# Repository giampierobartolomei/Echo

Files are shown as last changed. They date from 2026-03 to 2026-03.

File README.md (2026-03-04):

# Echo – An AI‑based Toy for Symbolic Play Recognition and Data Collection 

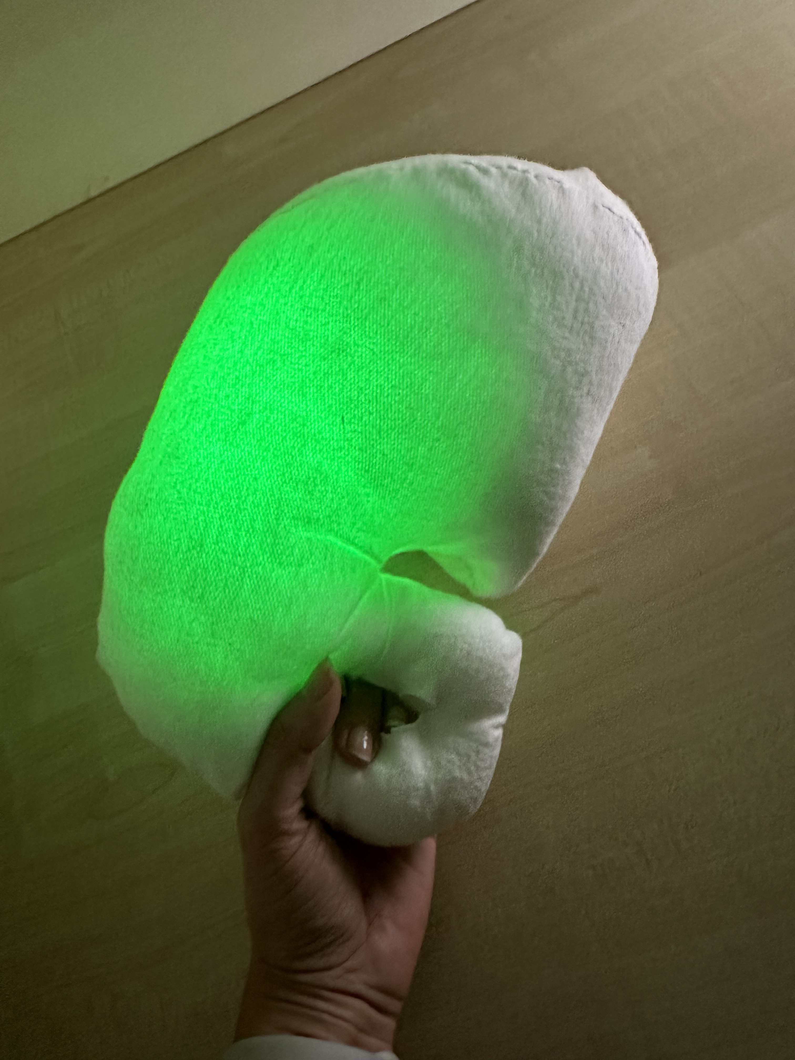
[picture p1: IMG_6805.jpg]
Echo Prototype


---

## Overview
**Echo** is an intelligent toy designed to recognize and log **symbolic play activities** in children with Autism Spectrum Conditions.  
It combines onboard sensors, real‑time classification, and a custom Android application to support both **therapy** and **data collection** within the IM‑TWIN research framework.

Echo detects and classifies manipulative play gestures using embedded machine‑learning models trained on inertial data. The system provides **sound and light feedback**, while also logging structured data for offline analysis.

---

## Hardware Setup
- **Microcontroller:** ESP32 (with integrated MPU6050 IMU)  
- **Sensors:** MPU9265 sensor: 3‑axis accelerometer (±2 g) and gyroscope (±500 °/s), tilt angles 0–360°  
- **Outputs:** LEDs and speaker for multimodal feedback  
- **Prototype files:** `.fzz` breadboard, schematic, and PCB layouts are included in the electronics/ folder.  
- **Audio:** `mp3/` folder includes `.mp3` files for feedback behavior, please copy this folder in a microSD and put into the DFplayermini module.

---

## Firmware and Algorithms

### Folders and Functions
The firmware/ directory contains the Arduino sketch for Echo. This sketch integrates the motion‑classification model (already compiled into model.h) and controls the LEDs and DFPlayerMini. Simply open the .ino file in the Arduino IDE, install the required libraries, and upload it to your ESP32. No additional training is needed – the decision‑tree model is embedded and ready to run.

### Signal and Range
- Accelerometer: ±2 g (gravity compensation active)  
- Gyroscope: ±500 °/s  
- Tilt angles: 0–360°

## Android App (APK)

The app/ folder includes a prebuilt Android application (EchoApp.apk). Install this APK directly on an Android device (Android 8+ recommended). 

### Features
- Real‑time plotting of **tilt** and **accelerometer** data.  
- **Label selection buttons** for organizing recorded gestures.  
- Automatic creation of labeled log files.  
- Volume and LED sliders: LEDs turn on at startup, and users can control brightness and sound volume.  
- Bluetooth connection with Echo for real‑time classification feedback.

## 3D‑Printable Cover

The cover_3d/ directory provides STL files for a 3D‑printable cover/enclosure. Print the parts at 100 % scale using PLA or PETG, then assemble them around the ESP32 and DFPlayerMini according to the photographs in the folder. The cover is designed to protect the electronics and provide a child‑friendly form factor.

## Embedding

Use an e-form fabric, fill it with wadding and place the electronics in the flat base; make the led strip run over all the prototype.

## Data Workflow

1. Assemble the hardware following the electronics diagram and install the firmware from firmware/.

2. Copy the contents of the mp3/ folder onto a microSD card and insert it into the DFPlayerMini.

3. Install the EchoApp.apk on an Android device and pair it via Bluetooth with your ESP32.

4. Power on Echo. When gestures are performed, the device will classify them using the embedded model and provide audio/LED feedback.

5. Use the app to view live sensor data, adjust settings and log sessions for later analysis.

6. Export logged .csv files from the app if you wish to retrain or refine the model.

## Citations

**1. Giampiero Bartolomei, Beste Ozcan, Giovanni Granato, Gianluca Baldassarre, and Valerio Sperati. 2025. Echo: an AI-based toy to encourage symbolic play in children with Autism Spectrum Conditions. In Proceedings of the Nineteenth International Conference on Tangible, Embedded, and Embodied Interaction (TEI '25). Association for Computing Machinery, New York, NY, USA, Article 85, 1–6. https://doi.org/10.1145/3689050.3705987**  

**2. Bartolomei, G., Ozcan, B., Granato, G., Baldassarre, G., & Sperati, V. (2025). A proposal for an AI-based toy to encourage and assess symbolic play in autistic children. Behaviour & Information Technology, 44(14), 3390–3403. https://doi.org/10.1080/0144929X.2025.2523478**

---

## License
Code and documentation released under the **MIT License**.  
Audio and media assets under **CC BY 4.0**.

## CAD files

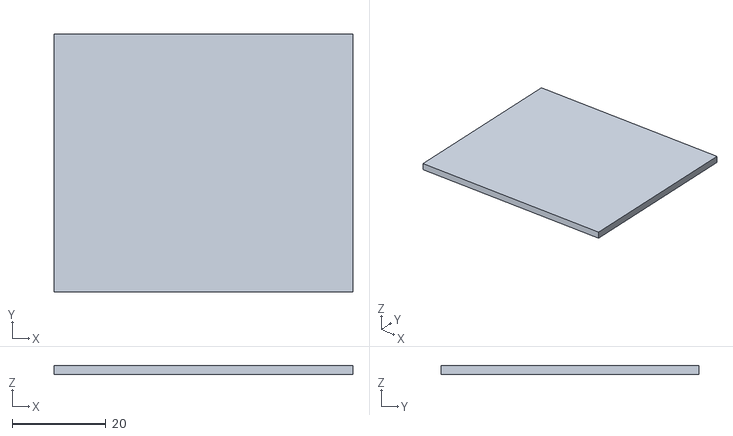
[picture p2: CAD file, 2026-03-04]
stl_file_cover/battery-cup1.stl
63.7 x 55.0 x 2.00

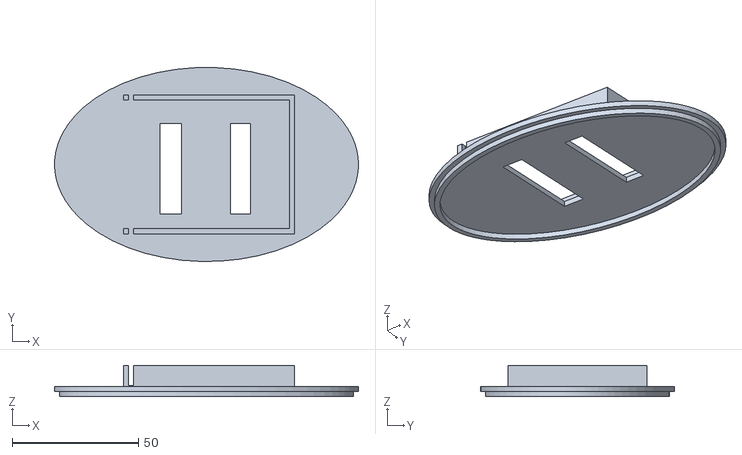
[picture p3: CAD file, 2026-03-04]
stl_file_cover/cup.stl
120.6 x 76.9 x 12.3

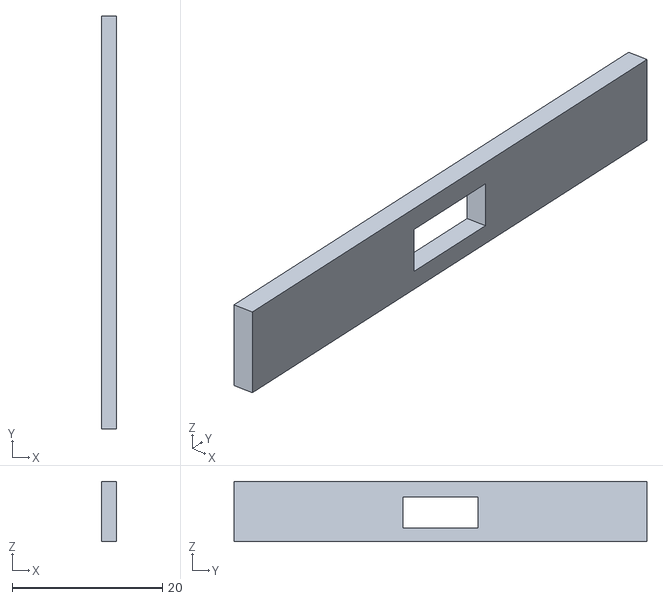
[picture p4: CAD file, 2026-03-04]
stl_file_cover/battery-cup2.stl
2.00 x 55.0 x 8.00

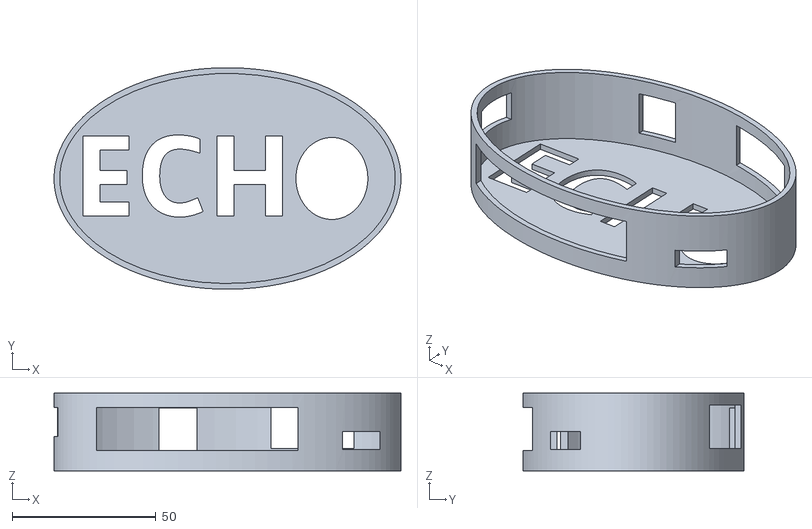
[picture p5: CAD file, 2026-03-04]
stl_file_cover/cover.stl
120.6 x 77.0 x 27.0

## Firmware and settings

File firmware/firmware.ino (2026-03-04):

//to load this code change this setting: arduino uno/Tools/Partition Scheme:HUGE APPS (3 MB no OTA/1 MB SPIFFS)
//Insert mp3 file in a folder named 'mp3' in the root path of a microSD. they are sorted by the date and hour of file uploading.
#include <BLEDevice.h>
#include <BLEUtils.h>
#include <BLEScan.h>
#include <BLEAdvertisedDevice.h>
#include <Arduino.h>
#include <arduinoFFT.h>
#include "model_alldata.h"  //change this line for test the other models
#include "Wire.h"
#include <MPU6050_light.h>
#include <BLEServer.h>
#include <deque>
#include <math.h>
#include "Bluetooth.h"
#include <Adafruit_NeoPixel.h>
#include "DFRobotDFPlayerMini.h"  //DFPlayermini_Fast can be an alternative
// CONSTANTS
#define INTERVAL 33
#define SAMPLES 16  // Number of samples processed
#define SAMPLING_FREQUENCY 30
#define CLASSIFICATION_BUFFER_SIZE 5  // Number of classification saved before to indicate wich class is the most rapresentative(Majority Voting) - DEFAULT VALUE
#define PIN_STRIP 13
#define NUMPIXELS 10
#define LED_LOG1 32 //RED
#define LED_LOG2 25 //YELLOW
#define potPin 34

//VARIABLES

//fft variables
float vReal[SAMPLES];  // Vettore per le componenti reali
float vImag[SAMPLES];  // Vettore per le componenti immaginarie
ArduinoFFT<float> FFT = ArduinoFFT<float>(vReal, vImag, SAMPLES, SAMPLING_FREQUENCY);
float features[3 * (SAMPLES / 2)];  // magnitude array that will cuncatenate fft results of the 3 features

// selected features - best 3 features ranked by a RandomForestClassifier
float feature1[SAMPLES];
float feature2[SAMPLES];
float feature3[SAMPLES];

int bufferIndex = 0;  // current index of samples saved in the buffer - from 0 to SAMPLES

// variables that store classification results
int classificationBuffer[CLASSIFICATION_BUFFER_SIZE];  // Buffer per le classificazioni
int classificationIndex = 0;                           // Saved Classification Index - from 0 to CLASSIFICATION_BUFFER_SIZE
int cbs = 5; //variable classification buffer size - 5 is default
MPU6050 mpu(Wire);
using namespace std;

// Temporal variable that defines acquisition cycles, f_s = 30 Hz; t_s = 33 ms
long prevMillis = 0;
unsigned long timestep = 0;
uint8_t timestepByte = 0;
int durata = 0;
int prev_durata = 0;
// bluetooth variables
bool identification = false;
void function_identify(bool identify);
void parse_commands(char* commands);
void function_(char* commands);
int current_function = 0;
bool send_diagnostic = false;
int lastReadValue = -1;  // BT trasmission command value

//byte data that will be sent to the Godot App
uint8_t log_values[11]; 
float x = 0;
float y = 0;
float z = 0;
float Gx = 0;
float Gy = 0;
float Gz = 0;
float Ax = 0;
float Ay = 0;
float Az = 0;
int classification = 0;
int mostFrequentClass = -1;

//Output Response Inizialization
Adafruit_NeoPixel strip = Adafruit_NeoPixel(NUMPIXELS, PIN_STRIP, NEO_GRB + NEO_KHZ800); //Led strip initialize
DFRobotDFPlayerMini player;  // Mp3 player initialize
Eloquent::ML::Port::DecisionTree clf; //if using model_all.h (with frog) micromlgen lilbrary to generate c function

//Volume settings Initializatioon
int potValue = 0;       
int volume = 0;        
int volumevalues[] = {0, 5, 10, 15, 20};

//Light intensity
int lightvalues[] = {0,32,64,128,255};
int lightvalue = 2;

void setup() {
  
  //fill the putput classification array with all -1 values, this value will be updated within the loop phase
  for (int i = 0; i < CLASSIFICATION_BUFFER_SIZE; i++) {
    classificationBuffer[i] = -1;  
  }
  
  Serial.begin(115200); //Serial comunication for debug

  // DF mini Player Inizialization (RX=16<-->TXdfmini & TX=17<-->RXdfmini)
  Serial2.begin(9600, SERIAL_8N1, 16, 17);  
  Serial.println("Connecting to DFplayer"); 
  while (!player.begin(Serial2)) {  //if dfplayer is connected the rest of the code can start to run
    Serial.print(".");
    delay(1000);
  }
  Serial.println(" DFplayer connected!");

  //Setting start Volume
  volume = 10;
  player.volume(volume);  

  //MPU9250 Inizialization
  Wire.begin();
  uint8_t status = mpu.begin();
  Serial.print(F("MPU9250 status: "));
  Serial.println(status);
  while (status != 0) {}  // if MPU is connected the rest of the code can run
  Serial.println(F("Calculating offsets, do not move MPU6050"));
  delay(1000);
  // mpu.upsideDownMounting = true; // uncomment this line if the MPU6050 is mounted upside-down
  mpu.calcOffsets();  // gyro and accelerometer
  Serial.println("Calibration Done!\n");

  //Initialization LED for comunication Android->Arduino the light up if the relative button in the app is pressed, 
  pinMode(LED_LOG1, OUTPUT);
  pinMode(LED_LOG2, OUTPUT);
  digitalWrite(LED_LOG1, LOW);  
  digitalWrite(LED_LOG2, LOW);       
  
  //last setup for BLE and LED strip
  setup_BLE_ESP32();

  //Strip led ON signal and setup
  strip.begin();
  for (int i = 0; i < strip.numPixels(); i++) {
    strip.setPixelColor(i, strip.Color(255, 0, 0));  // Accendi con un colore viola medio
  }
  strip.show();  // accensione
  delay(1500);
  for (int i = 0; i < strip.numPixels(); i++) {
    strip.setPixelColor(i, strip.Color(0, 0, 0));  // Spegni i LED
  }
  strip.show();   // Mostra i LED spenti
}

void loop() {

  //Setting the loop duration at frequency = 1/INTERVAL, this loop governate all the arduino loop function (they start and end together)
  long curMillis = millis();
  if (curMillis - prevMillis >= INTERVAL) {
    long int start = millis();
    
    // Volume Changing - ONLY if the potentiometer change its Value, the Volume of the speaker change its Value (This is important! if player.volume is called every loop, the loop duration gets bigger!!)
    potValue = analogRead(potPin);
    volume = mapfloat(potValue, 0, 4095, 0, 30);
    static int lastVolume = -1;
    if (volume != lastVolume) {
      player.volume(volume);
      lastVolume = volume;
      Serial.print("Volume updated at: ");
      Serial.println(volume);
    }

    //Sensor Readings
    mpu.update();
    x = float(mpu.getAngleX());
    y = float(mpu.getAngleY());
    z = float(mpu.getAngleZ());
    Gx = float(mpu.getGyroX());  //+- 500 deg/s
    Gy = float(mpu.getGyroY());
    Gz = float(mpu.getGyroZ());
    Ax = float(mpu.getAccX());  //+-2g
    Ay = float(mpu.getAccY());
    Az = float(mpu.getAccZ() - 1);  // -1 compensa l'effetto della gravità

    // filling samples buffer of the 3 selected features
    feature1[bufferIndex] = x;
    feature2[bufferIndex] = y;
    feature3[bufferIndex] = Gz;
    bufferIndex++;

    // Checking if the buffer is full, hen it is, the processing of the data start
    if (bufferIndex >= SAMPLES) {
      bufferIndex = 0;

      // FFT function Computation
      auto calculateFFT = [](const float input[], float magnitudes[], int offset) {
        for (int i = 0; i < SAMPLES; i++) {
          vReal[i] = input[i];
          vImag[i] = 0.0f;  // the Immaginary part is 0
        }
        FFT.compute(FFTDirection::Forward);
        FFT.complexToMagnitude();
        for (int i = 0; i < SAMPLES / 2; i++) {
          magnitudes[offset + i] = vReal[i];
        }
      };

      // FFT computation of the 3 features and concatenation in the 'features' variable.
      calculateFFT(feature1, features, 0);
      calculateFFT(feature2, features, SAMPLES / 2);
      calculateFFT(feature3, features, SAMPLES);
      
      /*for (int i = 0; i < 24; i++) {
      Serial.print("features[");
      Serial.print(i);
      Serial.print("]: ");
      Serial.println(features[i]);
    }
    */
      //Classify and saving the result in a buffer for Majority Voting
      classification = clf.predict(features);  
      classificationBuffer[classificationIndex] = classification;
      classificationIndex++;

      // When the buffer of the classification is full, the most rapresentative class is saved in the 'mostFrequentClass' variable
      if (classificationIndex >= cbs) {  //before there was CLASSIFICATION_BUFFER_SIZE
        int classCounts[4] = { 0, 0, 0, 0 };
        for (int i = 0; i < cbs; i++) { //before there was CLASSIFICATION_BUFFER_SIZE
          classCounts[classificationBuffer[i]]++;
        }
        int maxCount = 0;
        for (int i = 0; i < 4; i++) {
          if (classCounts[i] > maxCount) {
            maxCount = classCounts[i];
            mostFrequentClass = i;  //majority result
          }
        }

        // Conversion from a numerical label (0,1,2,3) to textual label for Serial Printing
        String classificationString;
        switch (mostFrequentClass) {
          case 0:
            classificationString = "AIRPLANE";
            for (int i = 0; i < strip.numPixels(); i++) {
              strip.setPixelColor(i, strip.Color(lightvalue, 0, 0));  // RED
              strip.show();                                    
            }
            player.play(1);  
            break;
          case 1:
            classificationString = "CAR";
            for (int i = 0; i < strip.numPixels(); i++) {
              strip.setPixelColor(i, strip.Color(lightvalue, 0, lightvalue));  // VIOLET
              strip.show();                                  
            }
            player.play(2);  
            break;
          case 2:
            classificationString = "FROG";
            for (int i = 0; i < strip.numPixels(); i++) {
              strip.setPixelColor(i, strip.Color(0, lightvalue, 0));  // GREEN
              strip.show();                                    
            }
            player.play(3);  
            break;
          case 3:
            classificationString = "IGNORING";
            for (int i = 0; i < strip.numPixels(); i++) {
              strip.setPixelColor(i, strip.Color(0, 0, lightvalue));  // BLUE
              strip.show();                                    
            }
            player.play(4);  
            break;
          default:
            classificationString = "UNKNOWN";  //useful for debug
            break;
        }

        //DEBUG PRINTS
        Serial.print("Activity: ");
        Serial.println(classificationString);

        classificationIndex = 0;
      }
    }
    

    // BT Transmission to Arduino
    String value = stringStreamCharacteristic->getValue();  // Simulate a reading
    if (!value.isEmpty()) {
      int readValue = atoi(value.c_str());
      if (readValue != lastReadValue) {  ///COMMAND: consecutive equal commands will not work!!!, this helps to have different commands

        if (readValue == 10){////COMMAND: Start log button will turn on the led strip (orange)
          Serial.println("Start Log");
          for (int i = 0; i < strip.numPixels(); i++) {
            strip.setPixelColor(i, strip.Color(255, 165, 0));  // Colore arancione
            strip.show();                                       
          }
          //reset all when start log is pressed
          bufferIndex=0;
          classificationIndex = 0; 
          classification = 9;
          mostFrequentClass = 9; 

        } else if (readValue == 20) {//COMMAND: Stop log button will turn on the led strip (orange)
          Serial.println("Stop Log");
          for (int i = 0; i < strip.numPixels(); i++) {
            strip.setPixelColor(i, strip.Color(255, 165, 0));  // Colore arancione
            strip.show();                                       
          }
        }  else if (readValue == 11) {///COMMAND: classification buffer size regulation (from 11 to 15)
          cbs=1;
        }  else if (readValue == 12) {
          cbs=2;
        }  else if (readValue == 13) {
          cbs=3;
        }  else if (readValue == 14) {
          cbs=4;
        }  else if (readValue == 15) {
          cbs=5;
        } else if (readValue == 21) {////COMMAND: volume intensity (from 21 to 25)
          player.volume(volumevalues[0]);
        }  else if (readValue == 22) {
          player.volume(volumevalues[1]);
        }  else if (readValue == 23) {
          player.volume(volumevalues[2]);
        }  else if (readValue == 24) {
          player.volume(volumevalues[3]);
        }  else if (readValue == 25) {
          player.volume(volumevalues[4]);
        }  else if (readValue == 31) {////COMMAND: light intensity (from 31 to 35)
          lightvalue = lightvalues[0];
        }  else if (readValue == 32) {
          lightvalue = lightvalues[1];
        }  else if (readValue == 33) {
          lightvalue = lightvalues[2];
        }  else if (readValue == 34) {
          lightvalue = lightvalues[3];
        }  else if (readValue == 35) {
          lightvalue = lightvalues[4];
        }  

        lastReadValue = readValue;  
      }
    }

    // BT Transmission to Android
    log_values[0] = static_cast<uint8_t>(mapfloat(Ax, -2, 2, 0, 255));
    log_values[1] = static_cast<uint8_t>(mapfloat(Ay, -2, 2, 0, 255));
    log_values[2] = static_cast<uint8_t>(mapfloat(Az, -2, 2, 0, 255)); 
    log_values[3] = static_cast<uint8_t>(mapAngleToByte(x));
    log_values[4] = static_cast<uint8_t>(mapAngleToByte(y));
    log_values[5] = static_cast<uint8_t>(mapAngleToByte(z));
    log_values[6] = static_cast<uint8_t>(mapfloat(Gx, -500, 500, 0, 255));
    log_values[7] = static_cast<uint8_t>(mapfloat(Gy, -500, 500, 0, 255));
    log_values[8] = static_cast<uint8_t>(mapfloat(Gz, -500, 500, 0, 255));
    log_values[9] = static_cast<uint8_t>(classification); //single classification result
    log_values[10] = static_cast<uint8_t>(mostFrequentClass); //majority voting result
    logCharacteristic->setValue(log_values, 11);
    logCharacteristic->notify();
    
    
    

    long int ende = millis();
    durata = ende - start;
    prev_durata = durata;
    Serial.print("Durata ciclo: "); //debug print for ms passed for cicle
    Serial.println(durata);
    prevMillis = curMillis;
    timestep++;

    timestepByte++;
  }
}

float mapfloat(float x, float in_min, float in_max, float out_min, float out_max) {
  return (x - in_min) * (out_max - out_min) / (in_max - in_min) + out_min;
}

float euler_to_byte(float angle_in_degrees) {
  // Normalizza l'angolo tra 0 e 360 gradi
  float normalized_angle = angle_in_degrees;
  while (normalized_angle >= 360.0) {
    normalized_angle -= 360.0;
  }
  while (normalized_angle < 0.0) {
    normalized_angle += 360.0;
  }

  // Mappa [0, 360] a [0, 255]
  float byte_value = (normalized_angle / 360.0) * 255.0;

  return byte_value;
}

float mapAngleToByte(float angle_degrees) {
  // Normalizza l'angolo tra [0, 360)
  while (angle_degrees >= 360.0) {
    angle_degrees -= 360.0;
  }
  while (angle_degrees < 0.0) {
    angle_degrees += 360.0;
  }

  // Mappa [0, 360) a [0, 255] byte range centrato attorno a 128
  uint8_t byte_value = (uint8_t)((angle_degrees / 360.0) * 255 + 128) % 256;

  return byte_value;
}

void write_float(uint8_t* buff, const float value) {
  const uint8_t* addr = reinterpret_cast<const uint8_t*>(&value);
  for (int i = 0; i != 4; i++)
    *buff++ = *addr++;
}

void parse_commands(char* commands) {
  Serial.print("[DEBUG][Lokahi.ino] parse_commands()\n\t");
  Serial.print("...parsing command, whole content is: ");
  Serial.print(commands);  // NOT SURE IT IS CORRECT THE PRINT OF A CHAR POINTER, CHECK!
  Serial.print("\n\t");

  // Splitting command in tokens separated by comma
  char* token = strtok(commands, ",");

  while (token != NULL) {
    String command = String(token);

    if (command.startsWith("Lokahi_test")) {
      Serial.print("Command: Lokahi test");
      Serial.println(command);
    } else if (command.startsWith("Lokahi_test_2")) {
      Serial.print("Command: Lokahi test_2");
      Serial.println(command);
    } else if (command.startsWith("Id")) {  // THIS IS the identification on device during connect phase! Id0 means stop identity
      Serial.print("Token is: ");
      Serial.println(command);

      command.remove(0, 2);
      int id = atoi(command.c_str());

      identification = id > 0;

      function_identify(identification);

      // This means that connection has been confirmed and we reset to initial function
      if (id == 0) {
        // In LOKAHI still we have no reset() neither InitFunction()
        // reset();
        // InitFunction5();
      } else {
        Serial.print("[WARNING!] command not recognized!\n\n");
      }
    }  // ...and so on for other commands

    // Last row of while loop
    token = strtok(NULL, ",");
  }  // Close while loop, and function parse_commands() ends
}

void function_identify(bool enable) {
  Serial.print("[DEBUG][Lokahi.ino] function_identify()\n\t");
  Serial.print("enable is: ");
  Serial.println(enable);
  Serial.println();

  if (enable) {
    // Add functionality here
  } else {
    // Add functionality here
  }
}

void Init_Function0() {
  current_function = 0;
}

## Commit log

2026-03-04 Revise README with updated hardware and app details
    Updated hardware setup and firmware sections in README.md. Added details about the Android app and 3D-printable cover.
2026-03-04 Clarify embedding instructions in README
    Updated instructions for embedding electronics in the prototype.
